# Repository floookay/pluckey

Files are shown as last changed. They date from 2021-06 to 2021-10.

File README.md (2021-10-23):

pluckey_logo

the pluckey is an ergodox like split keyboard with more pronounced columnal stagger and a vertical space key.  

I took inspiration from splitkbs Kyria and bishborias Ergodox design.

posterboy

## layout

The following physical layouts are supported:  
supported layouts  
And this is the default keymap as of now:  
keymap  
[Keyboard-Layout-Editor](http://www.keyboard-layout-editor.com/#/gists/13c9d00bd0c0c9e3fe3b3d8d98672ef9) [(raw)](https://gist.github.com/floookay/13c9d00bd0c0c9e3fe3b3d8d98672ef9)

## pcb

PCB rev1.1

The pcb is reversible and supports pcb mount MX style switches.  
It was designed using KiCAD and the following external libaries: [keebio-parts](https://github.com/keebio/Keebio-Parts.pretty) and [foostans kbd library](https://github.com/foostan/kbd)  
In order to assemble a pair you'll need the following hardware:

| amount | part | description |
|---|---|---|
| 66/68  | key switches | MX style |
| 66/68  | diodes | SMD or THT 1N4148(W) |
| 2 | mini USB ports | MX-54819-0519 |
| 2 | TRRS jacks | |
| 2 | tact switch | |
| 2 | pro micros | |
| 2 | micro usb connectors | or two micro usb cables |
| 8 | short wires | |

Additionally I'd recommend getting a pair of hotswapable headers for both pro micros.

**assembly:**  
Start by soldering the diodes, the headers, trrs jack and the mini usb port to the same side of the pcb. Make sure to clip the pins beforehand so they're flush on the other side.  
Now you can align your plate and solder in the switches.  
Plug the micro usb connector into the pro micro and align it according to the pinout on the solder mask. Depending on which headers you chose you might want to add electrical tape to the pro micro that's upside down so it doesnt touch the switch pins. Also nothe that you might have to solder on the controller at an angle if you're going with the default headers in order to be able to plug in the usb cable.  
Solder the wires to the micro usb connector (or cut open your existing cables) and solder the other side to the port headers according to the pinout on the solder mask.

<details>
<summary>more pictures</summary>

b-side  
pcbs soldered  
</details>
<br>

## case

### monolith

monolith  
The monolith case is a tray mounted design and 3d printable in two pieces: case and (optional) plate  
It was designed using FreeCAD (and some SolidPython until it got too complex for me) so please feel free to configure the case to your liking. It's fairly parametric set up so depending on what you want to achieve you'll have a few starting points.
In order to assemble the case you'll need the following additional hardware:

| amount | part |
|---|---|
| 8 | M2 4mm screws |
| 8 | M2 4mm spacers |
| 8+ | rubber feet |

**assembly:**  
After you soldered the PCB you can assemble the case. At first you're going to have to merge the spacers with the posts of the case. To do this heat up your soldering iron, position a spacer with a tweezer and press the spacer down with the tip of your soldering iron (make sure it's clean before this step). Do this with the other spacers, align the plate and pcb and fixate it with the screws. Lastly you can add the rubber feet according to your liking.

<details>
<summary>more pictures</summary>

inside  
usage position  
closeup  
backside  
bottom
</details>
<br>

### skeleton

skeleton  
The skeleton case is a simple open case for the pluckey pcb.  
The FreeCAD models are included in case you want to adjust the angle for example.  
All you need to do to assemble this case is to clip in the PCB. All you need to do to assemble this case is to clip in the PCB. If you're using encoders you'll have to cut the pins flush.

<details>
<summary>more pictures</summary>

usage  
closeup  
countryside  
</details>
<br>

### sandwich

sandwich  
The sandwich case is a laser cut acrylic case for the pluckey pcb from 3mm thick layers.
I also built this with FreeCAD so feel free to adjust. The kerf of the files is set to 0.2mm so you might need to adjust that.

| amount | part |
|---|---|
| 32 | M2 5+mm screws |
| 1 | set of cylindrical M2 standoffs (male + female) |
| 4 | diode legs |
| 8+ | rubber feet |

**assembly:**  
After you soldered the components to the PCB you can start soldering the switches with the plate in between. If you want to use a rotary encoder you'll have to enlargen the hole slightly with a dremel to fit its legs. As this is a 3mm plate I like to put small strips of cellular rubber vertically along the columns between the pcb and plate next to the switches. This prevents the switches from popping out of the plate. After you soldered the plate you can put screws in the top layer and gradually add the other layers, spacers and diode legs as soon as they fit. Use the male and female standoffs to create larger larger standoffs that fit each hole height (for the exact length opne „more pictures“). Lastly add the rubber feet, make sure that you place them at the same distance from the edge of each step.

<details>
<summary>more pictures</summary>

side profile  
backside  
freecad model  
standoff lengths  
</details>
<br>

## plate

If you want to print and use a plate I'd suggest you print the tolerance tester first (and maybe decrease the tolerances a bit).  
After you know the right margin for your printer you can adjust it in the plate model and export your plate in the desired layout.

## firmware

[QMK firmware](https://github.com/floookay/qmk_firmware/tree/master/keyboards/pluckey)

Compiling the keyboard (after setting up your build environment):

    make pluckey:default

Flashing the firmware:

    make pluckey:default:flash

## misc

> What where your goals behind designing this keyboard?

One thing I wanted to improve/avoid were keys that needed to be stabilized but at the same time have wider space keys to rest my thumbs on.

Another thing I wanted to achieve with this design was to be fairly flexible in terms of keycaps that can be used.  
Personally, I like the wider ergodox style modifier keys but keycap compability is unfortunatelly not that great beyond blank uniform caps.  
That's why I made the PCB compatible with all 1u keycaps that are offered in ortho keycap sets.

> What's next?

~~An acrylic sandwich-style case variants.~~  
I'm also thinking about making a pcb variant for low profile Choc switches with choc spacing.  

> What's the story behind the name?

I named the keyboard Pluckey after one of my favorite Animal Crossing villagers „Plucky“. The first letter of the logo represents Pluckys eye.

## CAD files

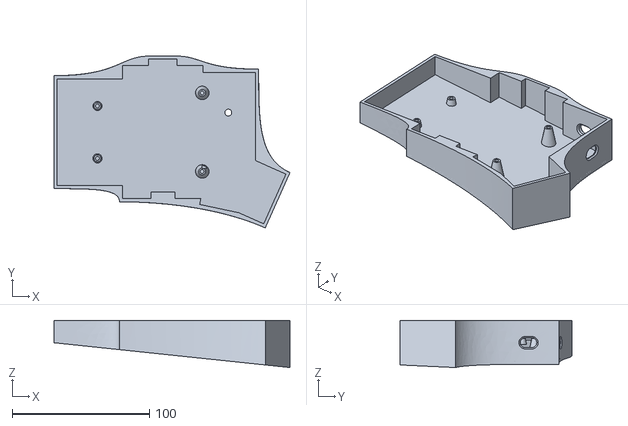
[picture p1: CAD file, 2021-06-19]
case/monolith/case_monoblock.stl
171.7 x 125.0 x 34.3

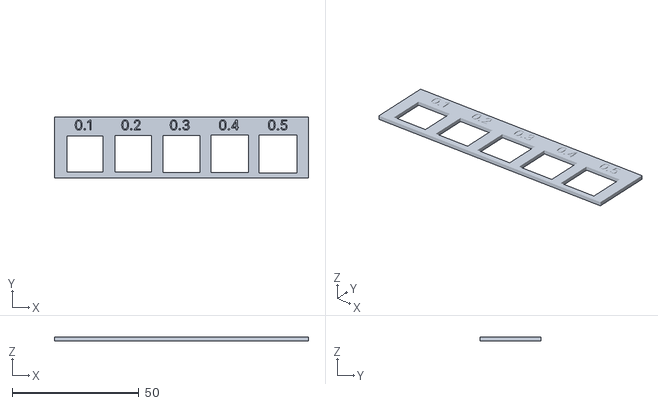
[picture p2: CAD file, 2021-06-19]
case/plate/tolerance tester.stl
100.3 x 24.1 x 1.50

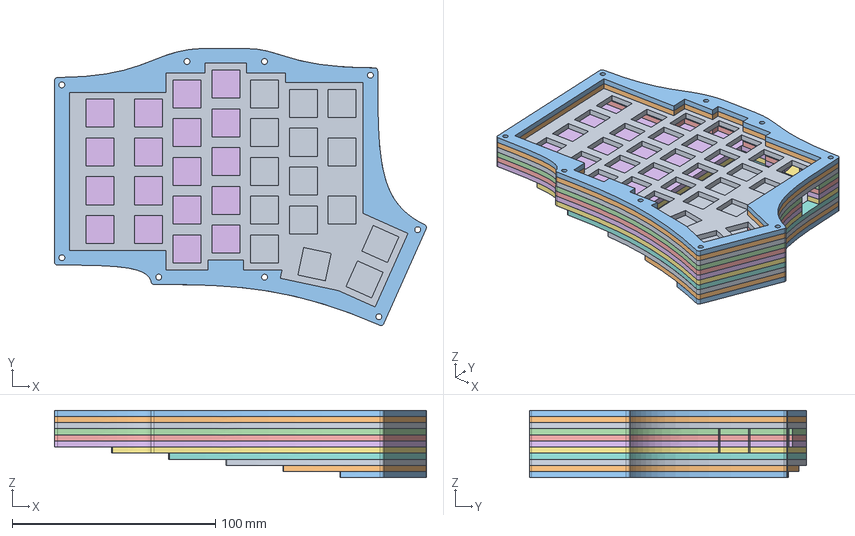
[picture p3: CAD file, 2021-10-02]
case/sandwich/case.FCStd
182.8 x 136.2 x 33.0 mm
plate layer
top layer
top layer 2
middle layer
middle layer 2
bottom layer
bottom layer 2
bottom layer 3
bottom layer 4
bottom layer 5
bottom layer 6
middle layer port edge
middle layer port edge 2
bottom layer port edge

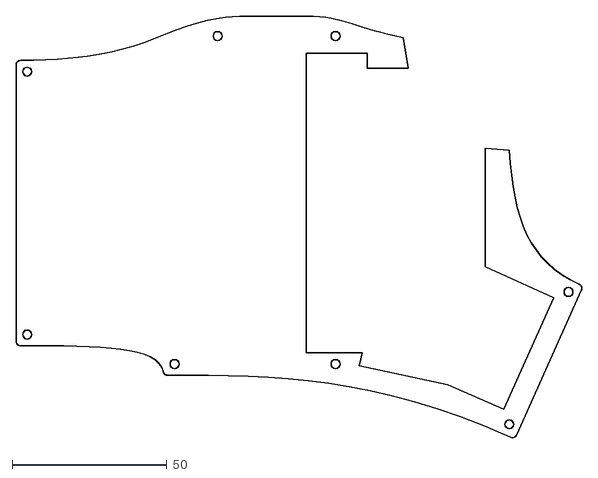
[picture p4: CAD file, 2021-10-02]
case/sandwich/layers/case-bottom layer.dxf
182.9 x 136.2

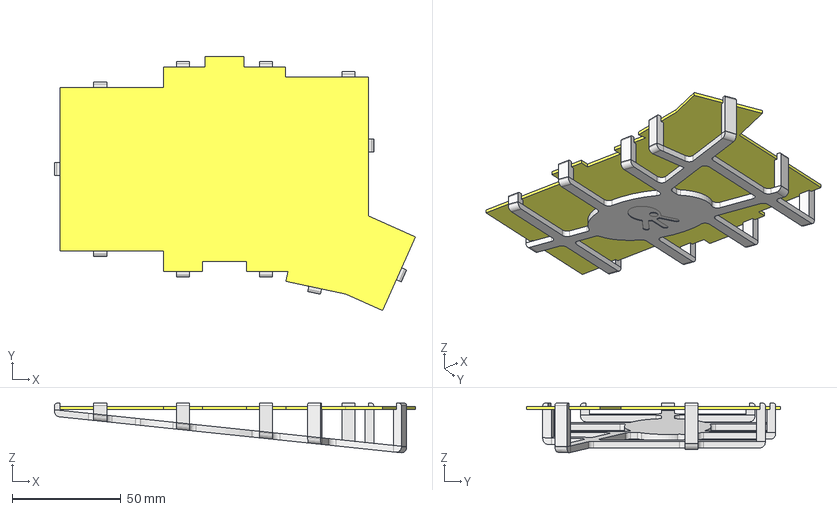
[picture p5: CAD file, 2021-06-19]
case/skeleton/skeleton.FCStd
166.1 x 116.9 x 22.8 mm
pcb
spine

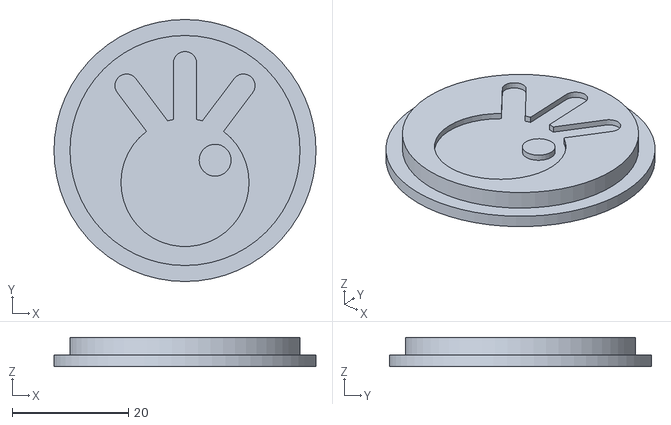
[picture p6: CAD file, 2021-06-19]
case/monolith/plug.stl
45.0 x 45.0 x 5.00

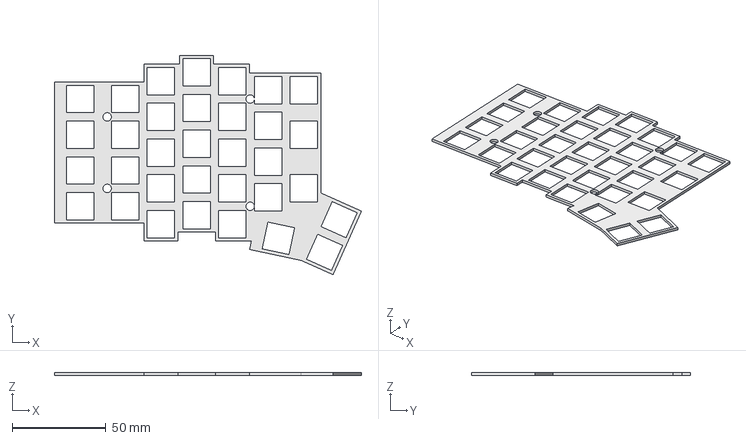
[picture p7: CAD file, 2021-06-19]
case/plate/plate.FCStd
163.6 x 116.9 x 1.50 mm

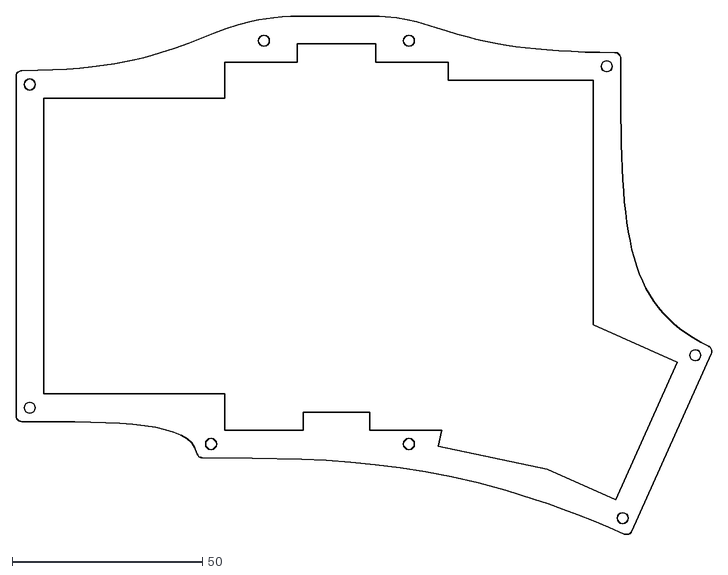
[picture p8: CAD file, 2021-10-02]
case/sandwich/layers/case-top layer 2.dxf
182.9 x 136.2

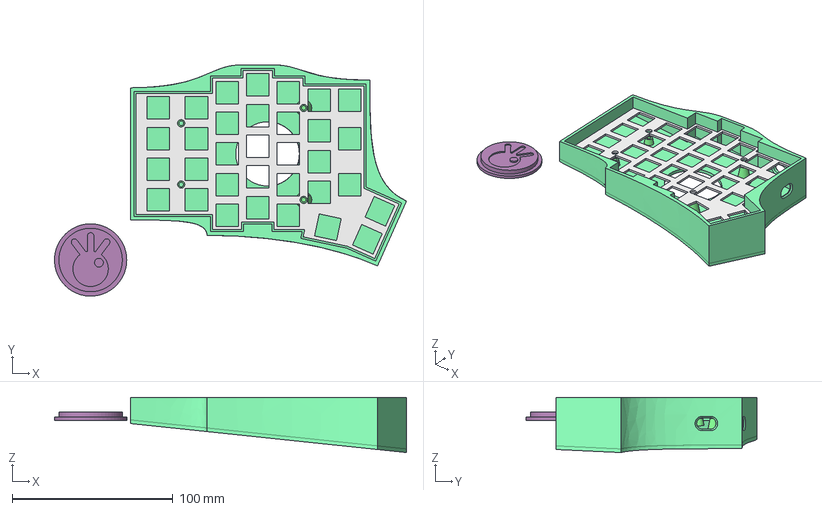
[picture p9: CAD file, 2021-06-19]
case/monolith/case.FCStd
218.9 x 143.9 x 34.3 mm
Plate
Fusion_posts
bottom
pluck (get it?)

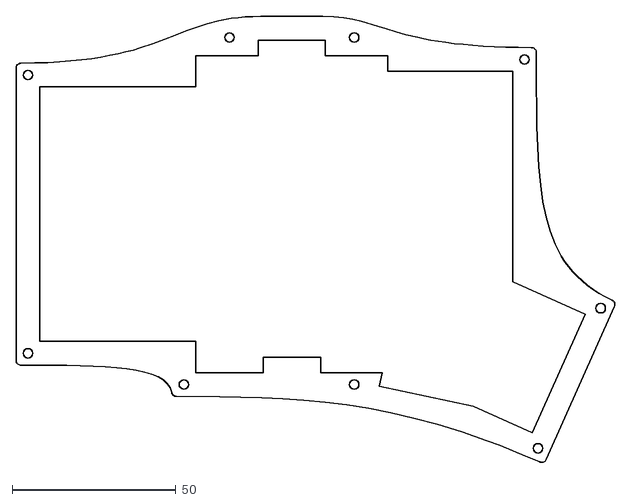
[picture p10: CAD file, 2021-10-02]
case/sandwich/layers/case-top layer.dxf
182.9 x 136.2

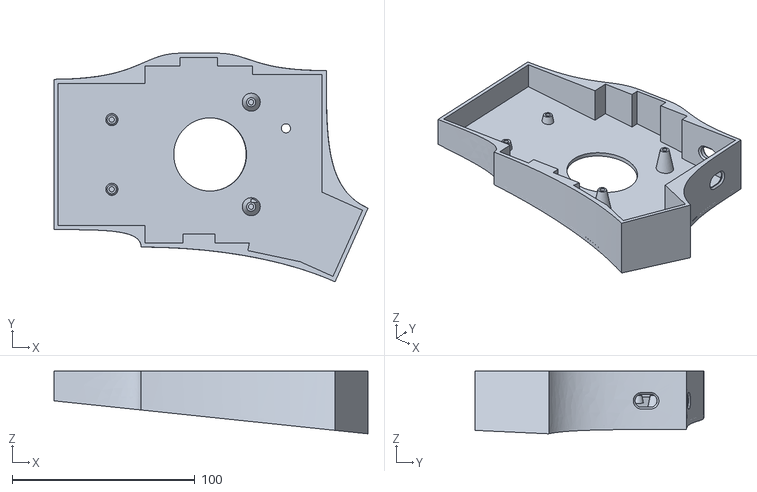
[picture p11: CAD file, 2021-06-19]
case/monolith/case_plug.stl
171.7 x 125.0 x 34.3

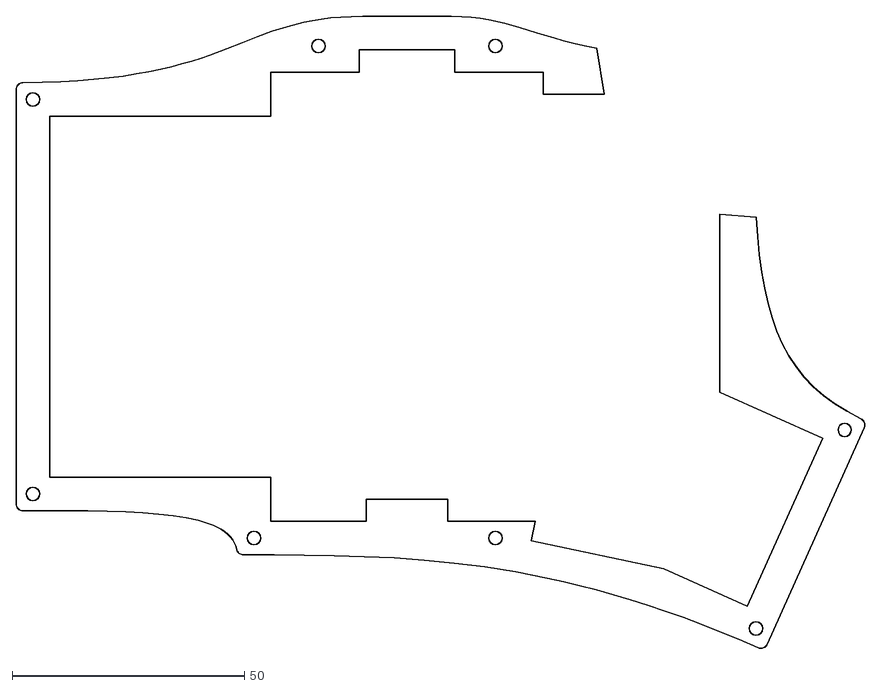
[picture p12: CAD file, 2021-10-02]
case/sandwich/layers/case-middle layer.dxf
182.9 x 136.2

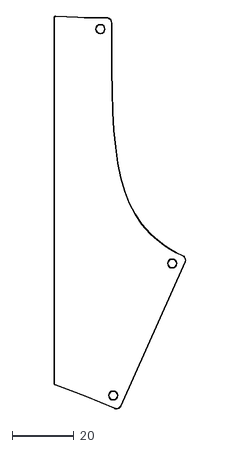
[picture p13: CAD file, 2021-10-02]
case/sandwich/layers/case-bottom layer 6.dxf
42.6 x 127.3

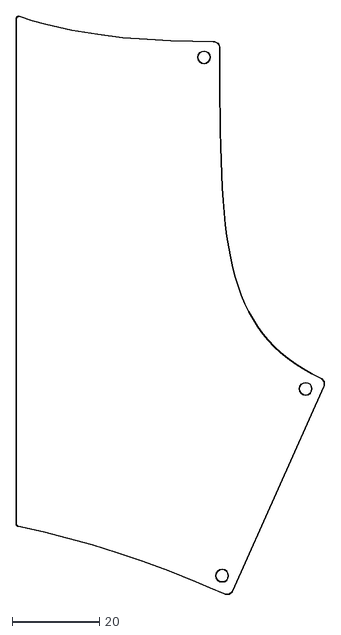
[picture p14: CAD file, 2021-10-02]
case/sandwich/layers/case-bottom layer 5.dxf
70.6 x 132.5

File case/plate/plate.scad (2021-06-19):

// Generated by SolidPython 1.1.1 on 2021-05-21 16:25:21


union() {
	cube(size = 0);
	translate(v = [14.2875000000, 0, 0]) {
		translate(v = [0, 0.0000000000, 0]) {
			union() {
				cube(size = 0);
				translate(v = [0, 9.5250000000, 0]) {
					difference() {
						cube(center = true, size = [28.5750000000, 19.0500000000, 4]);
						cube(center = true, size = [14, 14, 4.2000000000]);
					}
				}
				translate(v = [0, 28.5750000000, 0]) {
					difference() {
						cube(center = true, size = [28.5750000000, 19.0500000000, 4]);
						cube(center = true, size = [14, 14, 4.2000000000]);
					}
				}
				translate(v = [0, 47.6250000000, 0]) {
					difference() {
						cube(center = true, size = [28.5750000000, 19.0500000000, 4]);
						cube(center = true, size = [14, 14, 4.2000000000]);
					}
				}
				translate(v = [0, 66.6750000000, 0]) {
					difference() {
						cube(center = true, size = [28.5750000000, 19.0500000000, 4]);
						cube(center = true, size = [14, 14, 4.2000000000]);
					}
				}
			}
		}
	}
	translate(v = [38.1000000000, 0, 0]) {
		translate(v = [0, 0.0000000000, 0]) {
			union() {
				cube(size = 0);
				translate(v = [0, 9.5250000000, 0]) {
					difference() {
						cube(center = true, size = [19.0500000000, 19.0500000000, 4]);
						cube(center = true, size = [14, 14, 4.2000000000]);
					}
				}
				translate(v = [0, 28.5750000000, 0]) {
					difference() {
						cube(center = true, size = [19.0500000000, 19.0500000000, 4]);
						cube(center = true, size = [14, 14, 4.2000000000]);
					}
				}
				translate(v = [0, 47.6250000000, 0]) {
					difference() {
						cube(center = true, size = [19.0500000000, 19.0500000000, 4]);
						cube(center = true, size = [14, 14, 4.2000000000]);
					}
				}
				translate(v = [0, 66.6750000000, 0]) {
					difference() {
						cube(center = true, size = [19.0500000000, 19.0500000000, 4]);
						cube(center = true, size = [14, 14, 4.2000000000]);
					}
				}
			}
		}
	}
	translate(v = [57.1500000000, 0, 0]) {
		translate(v = [0, -9.5250000000, 0]) {
			union() {
				cube(size = 0);
				translate(v = [0, 9.5250000000, 0]) {
					difference() {
						cube(center = true, size = [19.0500000000, 19.0500000000, 4]);
						union() {
							cube(center = true, size = [14, 14, 4.2000000000]);
							translate(v = [0, 0, -2.0000000000]) {
								polyhedron(convexity = 5, faces = [[3, 2, 1, 0], [4, 5, 6, 7], [0, 1, 5, 4], [1, 2, 6, 5], [2, 3, 7, 6], [3, 0, 4, 7]], points = [[-4.1850000000, 8.7000000000, 0], [4.1850000000, 8.7000000000, 0], [4.1850000000, -8.7000000000, 0], [-4.1850000000, -8.7000000000, 0], [-4.1850000000, 7.0000000000, 3.2000000000], [4.1850000000, 7.0000000000, 3.2000000000], [4.1850000000, -7.0000000000, 3.2000000000], [-4.1850000000, -7.0000000000, 3.2000000000]]);
							}
						}
					}
				}
				translate(v = [0, 28.5750000000, 0]) {
					difference() {
						cube(center = true, size = [19.0500000000, 19.0500000000, 4]);
						cube(center = true, size = [14, 14, 4.2000000000]);
					}
				}
				translate(v = [0, 47.6250000000, 0]) {
					difference() {
						cube(center = true, size = [19.0500000000, 19.0500000000, 4]);
						cube(center = true, size = [14, 14, 4.2000000000]);
					}
				}
				translate(v = [0, 66.6750000000, 0]) {
					difference() {
						cube(center = true, size = [19.0500000000, 19.0500000000, 4]);
						cube(center = true, size = [14, 14, 4.2000000000]);
					}
				}
				translate(v = [0, 85.7250000000, 0]) {
					difference() {
						cube(center = true, size = [19.0500000000, 19.0500000000, 4]);
						cube(center = true, size = [14, 14, 4.2000000000]);
					}
				}
			}
		}
	}
	translate(v = [76.2000000000, 0, 0]) {
		translate(v = [0, -4.7625000000, 0]) {
			union() {
				cube(size = 0);
				translate(v = [0, 9.5250000000, 0]) {
					difference() {
						cube(center = true, size = [19.0500000000, 19.0500000000, 4]);
						cube(center = true, size = [14, 14, 4.2000000000]);
					}
				}
				translate(v = [0, 28.5750000000, 0]) {
					difference() {
						cube(center = true, size = [19.0500000000, 19.0500000000, 4]);
						cube(center = true, size = [14, 14, 4.2000000000]);
					}
				}
				translate(v = [0, 47.6250000000, 0]) {
					difference() {
						cube(center = true, size = [19.0500000000, 19.0500000000, 4]);
						cube(center = true, size = [14, 14, 4.2000000000]);
					}
				}
				translate(v = [0, 66.6750000000, 0]) {
					difference() {
						cube(center = true, size = [19.0500000000, 19.0500000000, 4]);
						cube(center = true, size = [14, 14, 4.2000000000]);
					}
				}
				translate(v = [0, 85.7250000000, 0]) {
					difference() {
						cube(center = true, size = [19.0500000000, 19.0500000000, 4]);
						cube(center = true, size = [14, 14, 4.2000000000]);
					}
				}
			}
		}
	}
	translate(v = [95.2500000000, 0, 0]) {
		translate(v = [0, -9.5250000000, 0]) {
			union() {
				cube(size = 0);
				translate(v = [0, 9.5250000000, 0]) {
					difference() {
						cube(center = true, size = [19.0500000000, 19.0500000000, 4]);
						cube(center = true, size = [14, 14, 4.2000000000]);
					}
				}
				translate(v = [0, 28.5750000000, 0]) {
					difference() {
						cube(center = true, size = [19.0500000000, 19.0500000000, 4]);
						cube(center = true, size = [14, 14, 4.2000000000]);
					}
				}
				translate(v = [0, 47.6250000000, 0]) {
					difference() {
						cube(center = true, size = [19.0500000000, 19.0500000000, 4]);
						cube(center = true, size = [14, 14, 4.2000000000]);
					}
				}
				translate(v = [0, 66.6750000000, 0]) {
					difference() {
						cube(center = true, size = [19.0500000000, 19.0500000000, 4]);
						cube(center = true, size = [14, 14, 4.2000000000]);
					}
				}
				translate(v = [0, 85.7250000000, 0]) {
					difference() {
						cube(center = true, size = [19.0500000000, 19.0500000000, 4]);
						cube(center = true, size = [14, 14, 4.2000000000]);
					}
				}
			}
		}
	}
	translate(v = [114.3000000000, 0, 0]) {
		translate(v = [0, 4.7625000000, 0]) {
			union() {
				cube(size = 0);
				translate(v = [0, 9.5250000000, 0]) {
					difference() {
						cube(center = true, size = [19.0500000000, 19.0500000000, 4]);
						cube(center = true, size = [14, 14, 4.2000000000]);
					}
				}
				translate(v = [0, 28.5750000000, 0]) {
					difference() {
						cube(center = true, size = [19.0500000000, 19.0500000000, 4]);
						cube(center = true, size = [14, 14, 4.2000000000]);
					}
				}
				translate(v = [0, 47.6250000000, 0]) {
					difference() {
						cube(center = true, size = [19.0500000000, 19.0500000000, 4]);
						cube(center = true, size = [14, 14, 4.2000000000]);
					}
				}
				translate(v = [0, 66.6750000000, 0]) {
					difference() {
						cube(center = true, size = [19.0500000000, 19.0500000000, 4]);
						cube(center = true, size = [14, 14, 4.2000000000]);
					}
				}
			}
		}
	}
	translate(v = [133.3500000000, 0, 0]) {
		translate(v = [0, 4.7625000000, 0]) {
			union() {
				cube(size = 0);
				translate(v = [0, 14.2875000000, 0]) {
					difference() {
						cube(center = true, size = [19.0500000000, 28.5750000000, 4]);
						cube(center = true, size = [14, 14, 4.2000000000]);
					}
				}
				translate(v = [0, 42.8625000000, 0]) {
					difference() {
						cube(center = true, size = [19.0500000000, 28.5750000000, 4]);
						cube(center = true, size = [14, 14, 4.2000000000]);
					}
				}
				translate(v = [0, 66.6750000000, 0]) {
					difference() {
						cube(center = true, size = [19.0500000000, 19.0500000000, 4]);
						cube(center = true, size = [14, 14, 4.2000000000]);
					}
				}
			}
		}
	}
	translate(v = [104.7750000000, 0, 0]) {
		translate(v = [0, 4.7625000000, 0]) {
			polyhedron(convexity = 5, faces = [[0, 2, 1], [0, 1, 4, 3], [1, 2, 5, 4], [2, 0, 3, 5], [3, 4, 5]], points = [[0, 0, -2.0000000000], [3.0369018749, 0, -2.0000000000], [0, -14.2875000000, -2.0000000000], [0, 0, 2.0000000000], [3.0369018749, 0, 2.0000000000], [0, -14.2875000000, 2.0000000000]]);
		}
	}
	translate(v = [107.8119018749, 0, 0]) {
		translate(v = [0, 4.7625000000, 0]) {
			rotate(a = 12.0000000000, v = [0, 0, -1]) {
				union() {
					translate(v = [28.5750000000, 0, 0]) {
						translate(v = [-14.2875000000, 0, 0]) {
							translate(v = [0, -9.5250000000, 0]) {
								difference() {
									cube(center = true, size = [28.5750000000, 19.0500000000, 4]);
									cube(center = true, size = [14, 14, 4.2000000000]);
								}
							}
						}
					}
					translate(v = [0, -19.0500000000, 0]) {
						translate(v = [28.5750000000, 0, 0]) {
							polyhedron(convexity = 5, faces = [[0, 2, 1], [0, 1, 4, 3], [1, 2, 5, 4], [2, 0, 3, 5], [3, 4, 5]], points = [[0, 0, -2.0000000000], [4.0789901917, 19.0500000000, -2.0000000000], [0, 19.0500000000, -2.0000000000], [0, 0, 2.0000000000], [4.0789901917, 19.0500000000, 2.0000000000], [0, 19.0500000000, 2.0000000000]]);
						}
					}
					translate(v = [0, -19.0500000000, 0]) {
						translate(v = [28.5750000000, 0, 0]) {
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

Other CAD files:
case/sandwich/layers/case-bottom layer 2.dxf
case/sandwich/layers/case-plate layer.dxf
case/sandwich/layers/case-bottom layer 4.dxf
case/sandwich/layers/case-middle layer port edge.dxf
case/plate/plate.stl
case/sandwich/layers/case-bottom layer 3.dxf
case/sandwich/layers/case-middle layer 2.dxf
case/skeleton/skeleton.stl

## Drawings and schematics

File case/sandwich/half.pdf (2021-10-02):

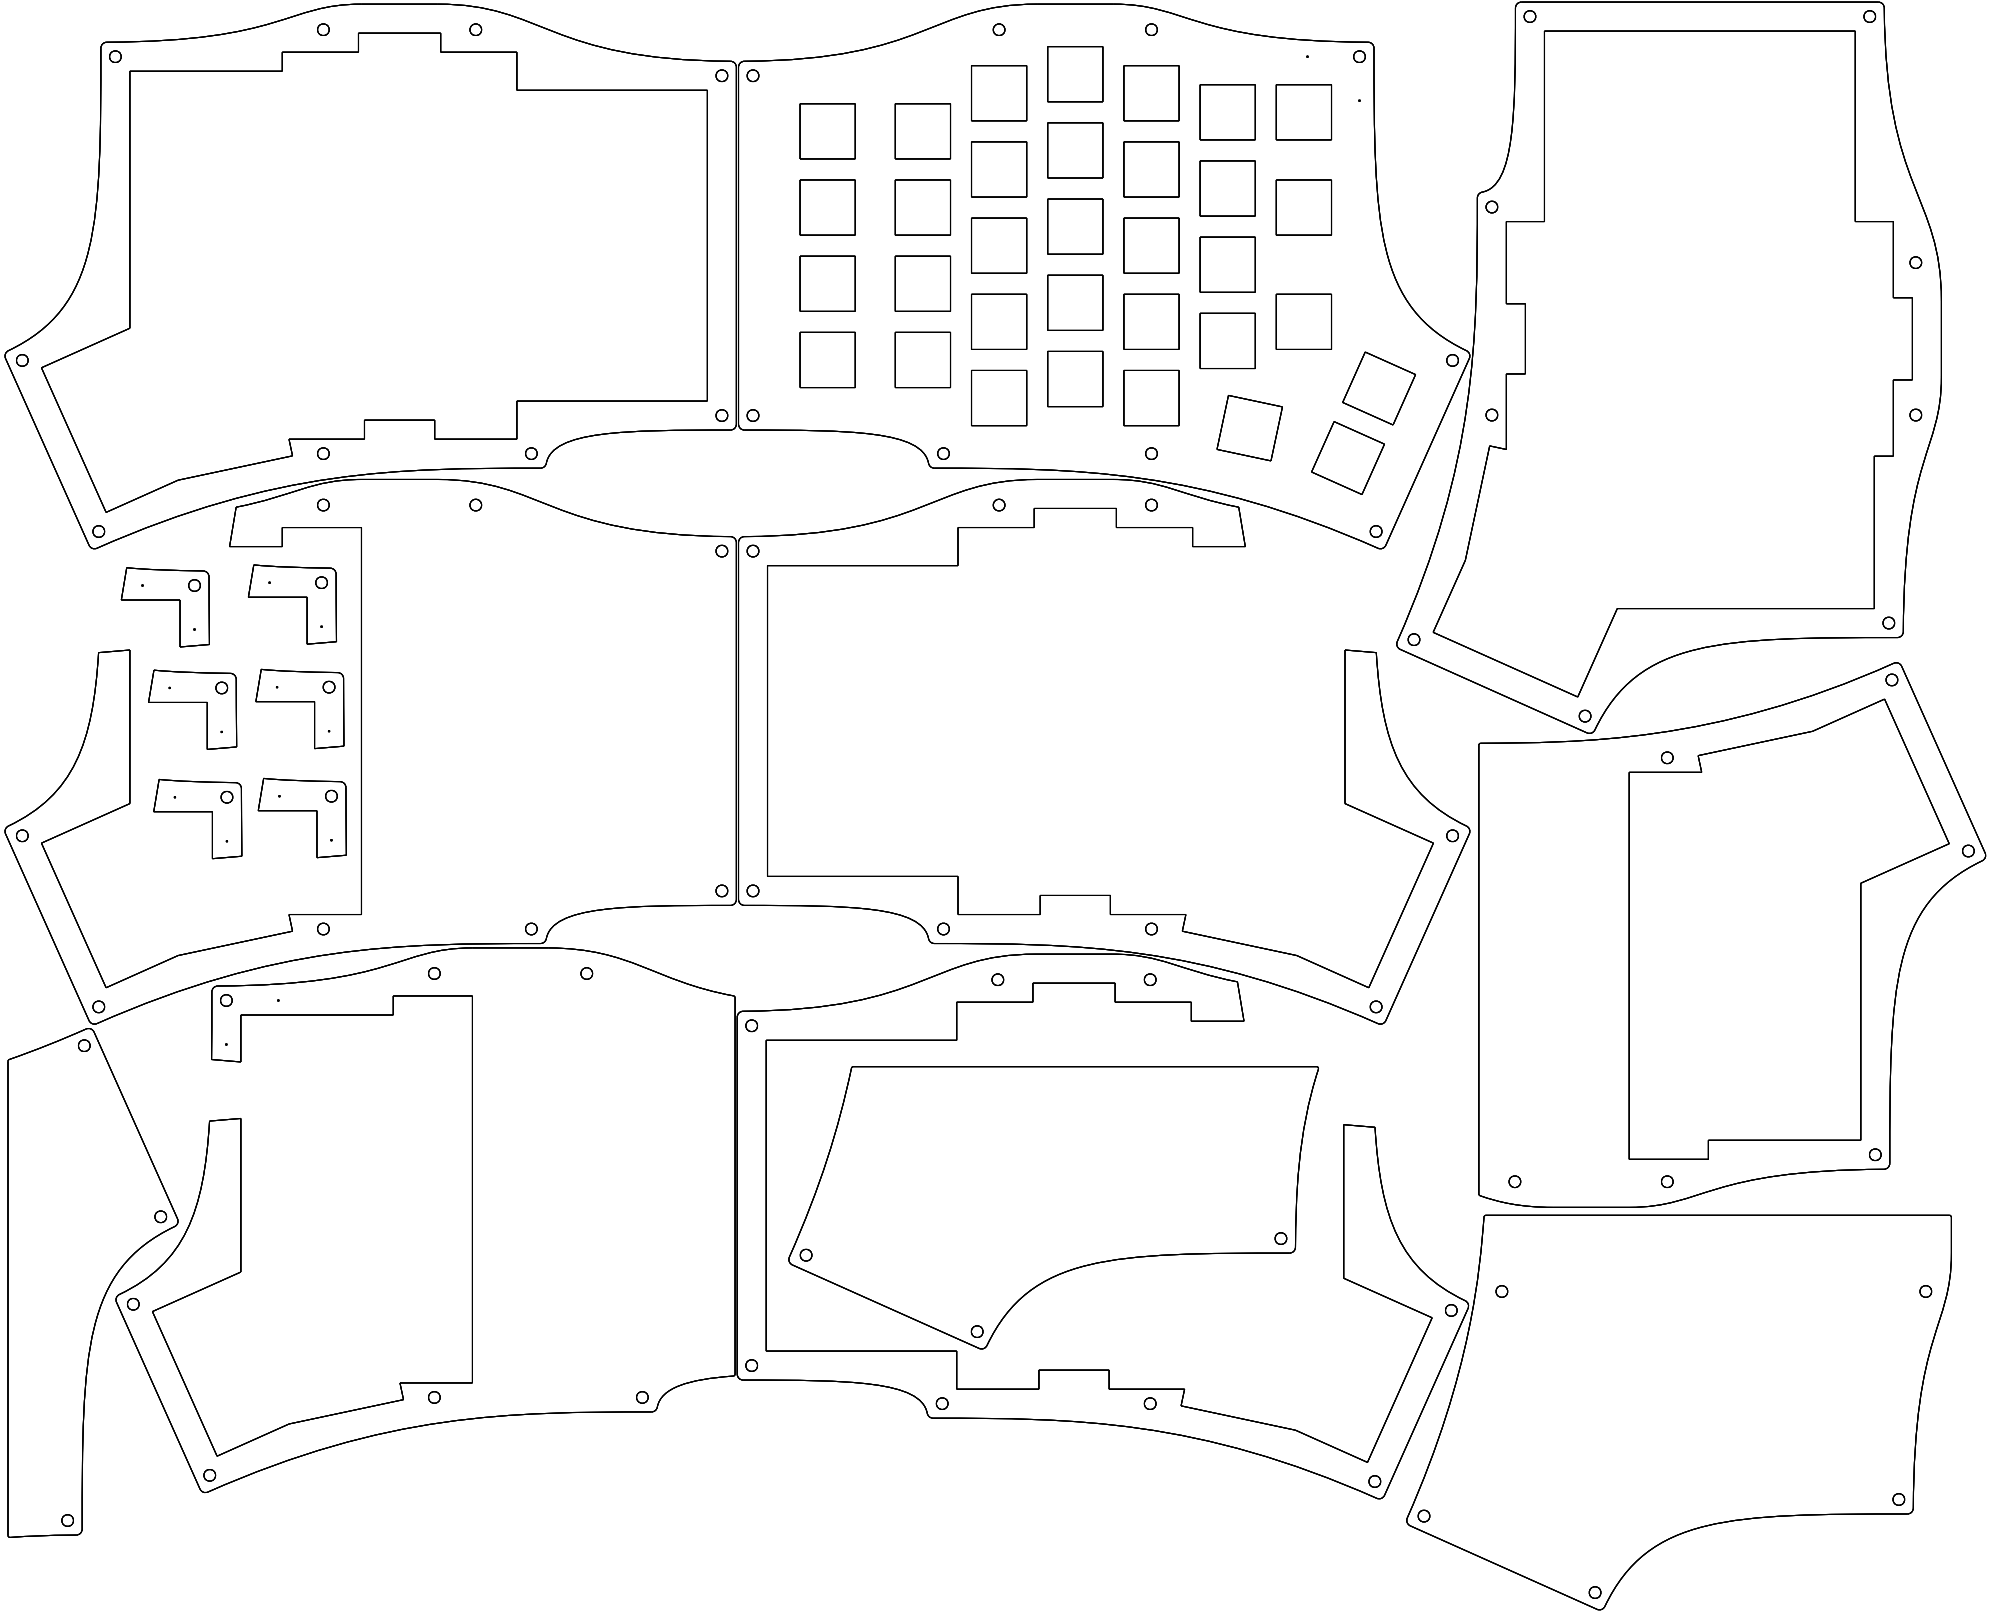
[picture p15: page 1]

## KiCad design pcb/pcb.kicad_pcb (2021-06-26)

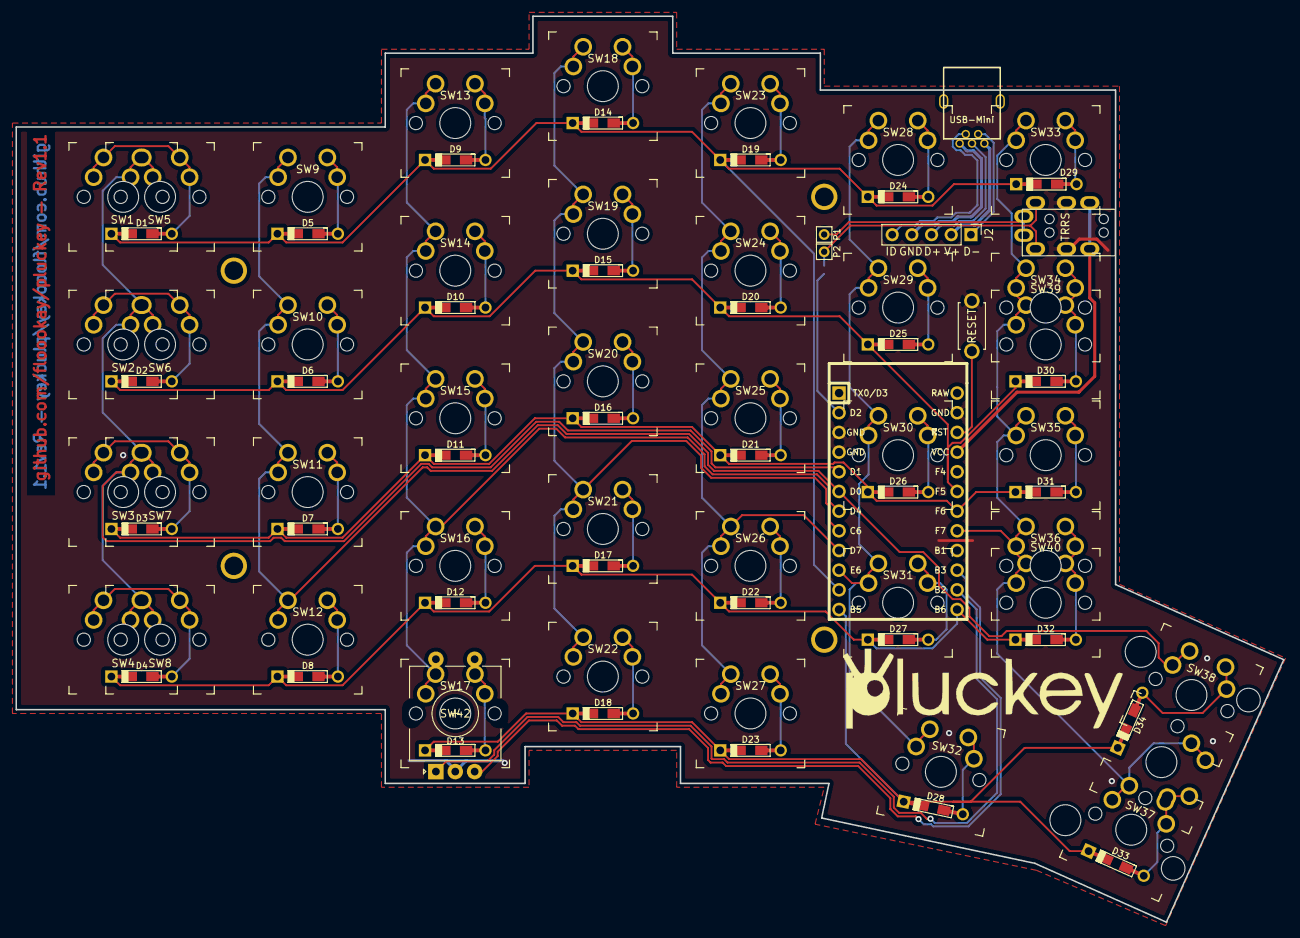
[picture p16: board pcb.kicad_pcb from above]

Board: 2 copper layers, 163.6 x 116.9 mm, 88 parts (1 on the bottom side), 59 nets.

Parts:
D1, D2, D3, D4, D5, D6, D7, D8, D9, D10, D11, D12, D13, D14, D15, D16, D17, D18, D19, D20, D21, D22, D23, D24, D25, D26, D27, D28, D29, D30, D31, D32, D33, D34: D; Diode-dual
H1, H2, H3, H4: MountingHole; m2.4_hole_plated
J1: USB-Mini; USB-Mini-B_2leg
J2: Conn_01x05; PinHeader_1x05_P2.54mm_Vertical
JP1: Jumper; JPC2
P1: i2c-pin1; 1pin_conn
P2: i2c-pin2; 1pin_conn
RSW1: SW_PUSH; ResetSW
SW1, SW2, SW3, SW4, SW5, SW6, SW7, SW8, SW9, SW10, SW11, SW12, SW13, SW14, SW15, SW16, SW17, SW18, SW19, SW20, SW21, SW22, SW23, SW24, SW25, SW26, SW27, SW28, SW29, SW30, SW31, SW32, SW33, SW34, SW35, SW36, SW37, SW38, SW39, SW40, SW41: SW_Push; SW_MX_reversible
SW42: Rotary_Encoder_Switch; RotaryEncoder_Alps_EC11E-Switch_Vertical_H20mm
U1: ProMicro; ArduinoProMicro
U2: TRRS; MJ-4PP-9

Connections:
/col0: SW1.2, SW2.2, SW3.2, SW4.2, SW5.1, SW6.1, SW7.1, SW8.1, U1.5
/col1: SW9.1, SW10.1, SW11.1, SW12.1, SW38.1, U1.6
/col2: SW13.1, SW14.1, SW15.1, SW16.1, SW17.1, SW42.S2, U1.7
/col3: SW18.1, SW19.1, SW20.1, SW21.1, SW22.1, U1.8
/col4: SW23.1, SW24.1, SW25.1, SW26.1, SW27.1, U1.9
/col5: SW28.1, SW29.1, SW30.1, SW31.1, SW32.1, U1.10
/col6: SW33.1, SW34.1, SW35.1, SW36.1, SW37.1, SW39.1, SW40.1, SW41.1, U1.17
/data: JP1.1, U1.2
/re0: SW42.B, U1.15
/re1: SW42.A, U1.14
/reset: RSW1.1, U1.22
/row0: D1.1, D5.1, D9.1, D14.1, D19.1, D24.1, D29.1, U1.11
/row1: D2.1, D6.1, D10.1, D15.1, D20.1, D25.1, D30.1, U1.19
/row2: D3.1, D7.1, D11.1, D16.1, D21.1, D26.1, D31.1, U1.18
/row3: D4.1, D8.1, D12.1, D17.1, D22.1, D27.1, D32.1, U1.13
/row4: D13.1, D18.1, D23.1, D28.1, D33.1, D34.1, U1.12
GND: RSW1.2, SW42.C, U1.3, U1.4, U1.23, U2.3
unnamed: D1.2, SW1.1, SW5.2
unnamed: D2.2, SW2.1, SW6.2
unnamed: D3.2, SW3.1, SW7.2
unnamed: D4.2, SW4.1, SW8.2
unnamed: D5.2, SW9.2
unnamed: D6.2, SW10.2
unnamed: D7.2, SW11.2
unnamed: D8.2, SW12.2
unnamed: D9.2, SW13.2
unnamed: D10.2, SW14.2
unnamed: D11.2, SW15.2
unnamed: D12.2, SW16.2
unnamed: D13.2, SW17.2, SW42.S1
unnamed: D14.2, SW18.2
unnamed: D15.2, SW19.2
unnamed: D16.2, SW20.2
unnamed: D17.2, SW21.2
unnamed: D18.2, SW22.2
unnamed: D19.2, SW23.2
unnamed: D20.2, SW24.2
unnamed: D21.2, SW25.2
unnamed: D22.2, SW26.2
unnamed: D23.2, SW27.2
unnamed: D24.2, SW28.2
unnamed: D25.2, SW29.2
unnamed: D26.2, SW30.2
unnamed: D27.2, SW31.2
unnamed: D28.2, SW32.2
unnamed: D29.2, SW33.2
unnamed: D30.2, SW34.2, SW39.2
unnamed: D31.2, SW35.2
unnamed: D32.2, SW36.2, SW40.2
unnamed: D33.2, SW37.2, SW41.2
unnamed: D34.2, SW38.2
unnamed: J1.1, J2.2
unnamed: J1.2, J2.1
unnamed: J1.3, J2.3
unnamed: J1.4, J2.5
unnamed: J1.5, J2.4
unnamed: JP1.2, P2.1, U2.2
unnamed: P1.1, U2.1
VCC: U1.21, U2.4

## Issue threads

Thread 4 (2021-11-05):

Hotswap?

Geobert, 2021-11-05:
Hi,

this board looks interesting!

Is there a hotswap version of this board? I have switches that I can reuse from a Sofle and I'd like to keep the possibility to reuse them on another board :)

Shahabaz-Bagwan, 2021-11-06:
No, you need to use mill max to make it hotswap. This thing is already discussed in wireless issue, kindly read that whole thread.

Closed 2021-11-26.

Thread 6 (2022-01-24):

Help needed!

aldecode, 2022-01-24:
Hi! I will say right away that I am a complete beginner, but I always wanted to do something like this. I very liked your layout, but for me will be great to add 2 more buttons on each side. It would be great if you could help me with this :)
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

floookay, 2022-01-24:
Hi,

sure, I can guide you on what needs to be done:
First you’d need to add the two extra keys to the matrix of the pcb. You can do that with kicad and eeschema. You probably have to add another column though because I mapped a thumb key there iirc in order to reduce the amount of needed column pins.
After you’ve done that you can edit the pcb itself with pcbeditor by importing the new schema. Set the grid to 19.05/8mm and set the offset to the position of one of the outermost keys.
Now you can move the new keys to the right positions and update the traces.
You can run the built in check once your done to check if you missed something.

For the case you’d be probably better of creating something new entirely.
I don’t think the current cases (except maybe skeleton) are editable in a way to add those keys efficiently.
For a new case I would open the mono case file, delete all parts except the plate, update said plate with the new keys and build from there.

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

aldecode, 2022-01-24:
> Hi, sure, I can guide you on what needs to be done: First you’d need to add the two extra keys to the matrix of the pcb. You can do that with kicad and eeschema. You probably have to add another column though because I mapped a thumb key there iirc in order to reduce the amount of needed column pins. After you’ve done that you can edit the pcb itself with pcbeditor by importing the new schema. Set the grid to 19.05/8mm and set the offset to the position of one of the outermost keys. Now you can move the new keys to the right positions and update the traces. You can run the built in check once your done to check if you missed something. For the case you’d be probably better of creating something new entirely. I don’t think the current cases (except maybe skeleton) are editable in a way to add those keys efficiently. For a new case I would open the mono case file, delete all parts except the plate, update said plate with the new keys and build from there.

Sounds super complicated to me :) Apparently I'll have to use the option as it is. But thanks for the mini-guide, I think it might be useful to me in the future

floookay, 2022-01-24:
Yeah, it’s a quite a bit of work in this case. But if you have any specific questions feel free to email me :)

Also, if you’re starting with pcb design I’d recommend this guide: https://github.com/ruiqimao/keyboard-pcb-guide
It helped me greatly when I started

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

aldecode, 2022-01-24:
@floookay many thanks!

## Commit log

2021-04-05 added basic plate generator functions
2021-04-06 renamed case file
2021-04-09 finished basic plate files
2021-04-11 added rotary encoder support
2021-04-11 increased middle finger stagger
2021-04-18 reworked holes
2021-04-24 added first version of the case
    [case.FCStd]
2021-04-24 added ergo plate dxf
    [case-PlatePocket001.dxf]
2021-04-30 added alpha pcb files
    [case.FCStd, pcb.kicad_pcb, pcb.sch]
2021-05-01 finished case and pcb prototype
    [case-PlatePocket001.dxf, case.FCStd, case.stl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]
2021-05-02 added assembly instructions
2021-05-13 finalised pcb rev1.1
    added support for an encoder
    added support for a stablized 2u key on the double thumb keys
    [pcb.kicad_pcb, pcb.sch]
2021-05-21 reworked case with adjustable play between caps and walls
    (bottom plate missing)
    [case.FCStd, case_rev0.FCStd]
2021-05-21 restructered case folder
    [case.FCStd, case.stl, case_rev0.FCStd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]
2021-05-22 added skeleton case files
    [skeleton.FCStd, skeleton.stl]
2021-05-23 updated silkscreen text
    [pcb.kicad_pcb, pcb.sch]
2021-05-25 updated skeleton model
    [skeleton.FCStd, skeleton.stl]
2021-05-25 fixed pin header footprint
    [pcb.kicad_pcb]
2021-05-26 reworked monolith case
    [case.FCStd, case.stl, case_rev0.FCStd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]
2021-05-27 added finishing touches to case
    - updated the case height so switches dont show
    - made mounting posts conical for better support
    - slightly adjusted port cutout height
    - added a hole in the bottom for the reset switch
    [case.FCStd, case.stl]
2021-05-27 increased post hole size slightly
    [case.FCStd, case.stl]
2021-05-28 added an optional bottom plug with the pluckey logo
    If you're wondering why: a small test print got stuck so hard on the mat
    that I ripped a hole into it. Exactly in the middle of the printing bed… fml
    [case.FCStd, case_monoblock.stl, case_plug.stl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]
2021-05-28 took height of pro micro into account at a cone post
    [case.FCStd, case_monoblock.stl, case_plug.stl]
2021-05-29 updated gerbers
    [pcb-B_Cu.gbr, pcb-B_Mask.gbr, pcb-B_Paste.gbr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]
2021-06-19 reworked plate files
    [layout0.scad, layout1.scad, plate.FCStd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]
2021-06-19 init sandwich case
    [case.FCStd]
2021-06-26 added missing via…
    [pcb-B_Cu.gbr, pcb-B_Mask.gbr, pcb-B_Paste.gbr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]
2021-06-26 added rotary encoder support notice
2021-07-04 added first few layers
    [case.FCStd]
2021-07-04 added vector ergo plate file
2021-07-04 moved plate file
2021-07-17 finished basic case form
    [case.FCStd]
2021-07-23 finished laser cut case files
    [case-bottom layer 2.dxf, case-bottom layer 3.dxf, case-bottom layer 4.dxf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]
2021-07-23 updated readme with sandwich case info
2021-07-24 added second top layer
    [case-top layer 2.dxf, case.FCStd]
2021-09-11 increased clearance for spacers, simplified needed components for assembly
    [case.FCStd]
2021-10-02 added fillet to layers
    [case.FCStd]
2021-10-02 updated 2d files
    [case-bottom layer 2.dxf, case-bottom layer 3.dxf, case-bottom layer 4.dxf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]
2021-10-02 updated readme with sandwich case details & pics
2021-10-23 Updated sandwich case pictures
2022-01-28 added kicad 6 backup folder
